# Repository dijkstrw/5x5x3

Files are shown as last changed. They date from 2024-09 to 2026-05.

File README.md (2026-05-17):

5x5x3
-----

My third take on a 5x5 macro keyboard, built on top of ZMK / Zephyr. The board
is a custom 5x5 matrix carried by a nice!nano v2 module, with a rotary encoder
on the side and a 25-LED SK6803 strip behind the keys.

What this repo adds on top of stock ZMK lives in `zmk-config/` and is loaded as
an out-of-tree Zephyr module:

- **Per-key light groups**. Each of the 25 LEDs is assigned to a group
  (`DESKTOP`, `VOLUME`, `HID`, `BATTERY`, `LAYER`, `ENDPOINT`, `PROFILE`) via
  the `zmk,light-group` and `zmk,behavior-led-layout` bindings. The group's
  current value indexes into a per-group HSV palette (`zmk,color-group` +
  `zmk,behavior-hsv`), so the LED grid reflects keyboard state at a glance:
  desktop number, volume level, output endpoint, BLE profile, layer, caps/num
  lock, battery, etc.
- **Color effects**. `src/color-effect.c` implements smooth HSV transitions
  for state changes, so values fade rather than snap.
- **`lightgroup` shell command**. A Zephyr shell over USB CDC ACM
  exposing `lightgroup battery|desktop|endpoint|hid|
  layer|profile|volume <value>` allows the host to drive the LED state
  directly. This is needed to update `desktop` and can be used to
  debug the other states.
- **Custom board**. `boards/dijkstra/5x5x3` defines the
  nice!nano-based matrix, the rotary encoder node, and the SK6803 SPI
  LED strip.

Schematic
---------

A kicad schematic and layout for 2 boards lives in `schematic`. The
bottom board carries the nice!nano v2, battery, on/off switch,
blackmagic/arm swd programming port, and breaks out to connections for
the top board. The top board is carries Kailh v2 low profile switches,
sk6803 leds underneath each switch.

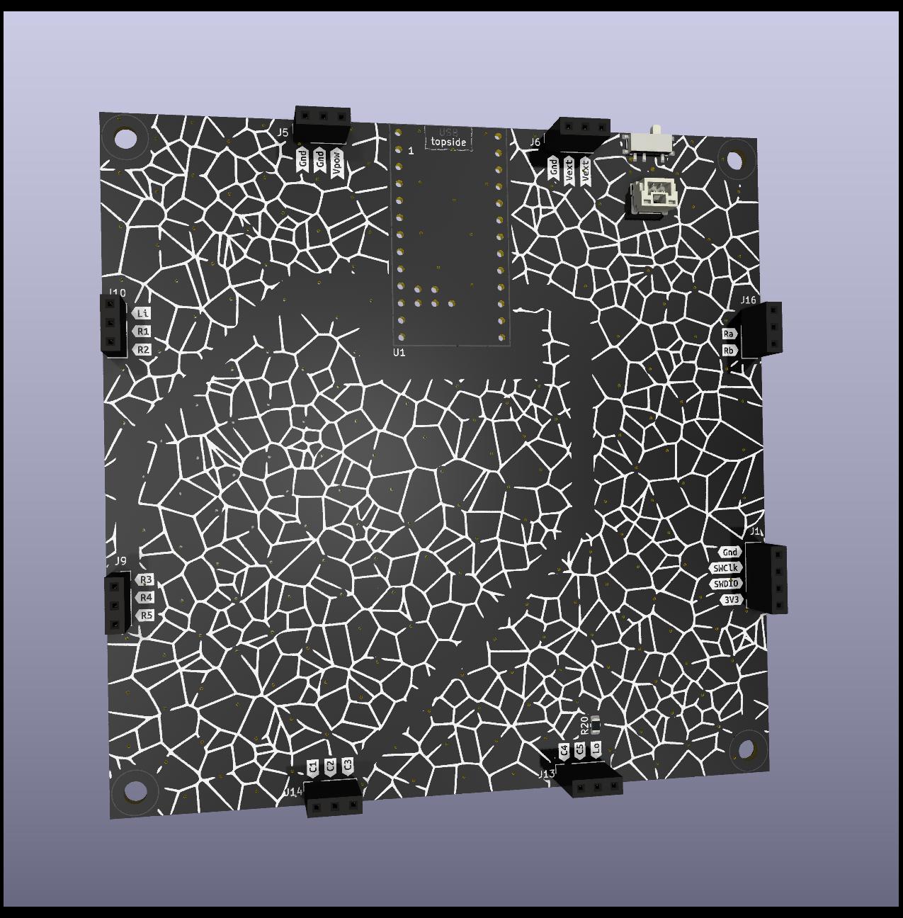
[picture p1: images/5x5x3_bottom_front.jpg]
Bottom board, front

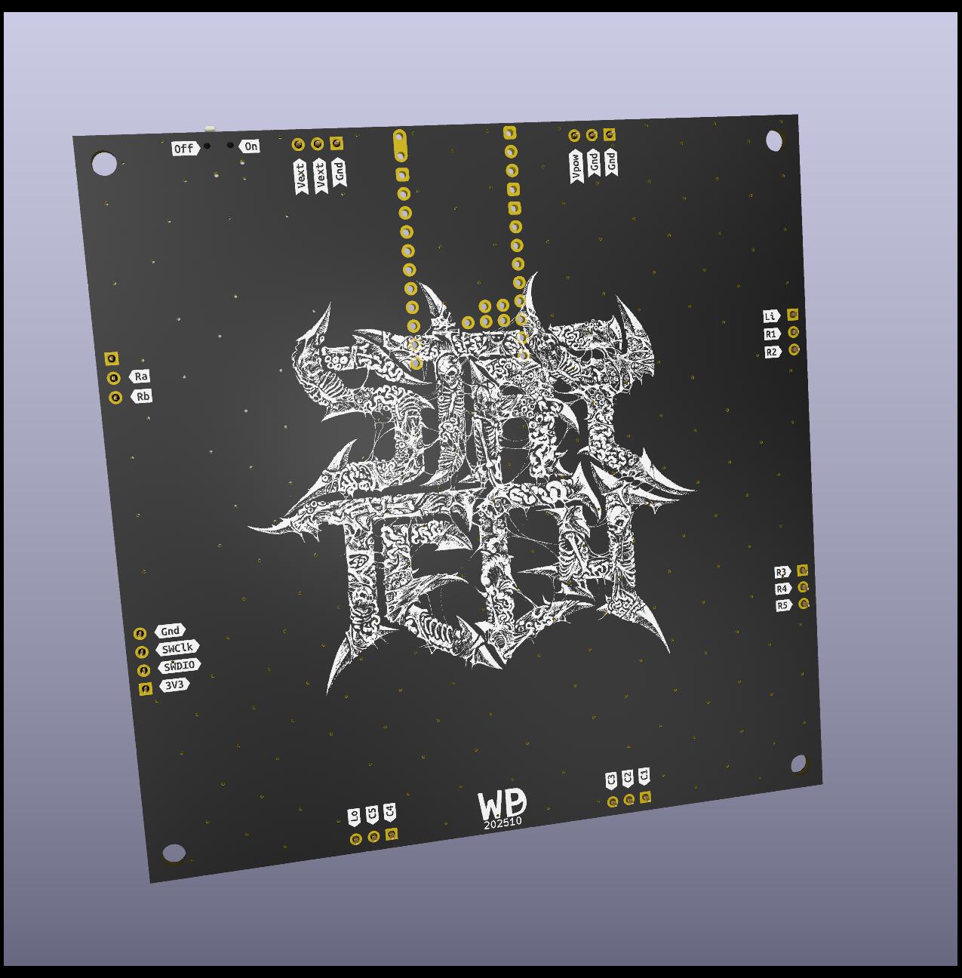
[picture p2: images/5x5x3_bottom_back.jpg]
Bottom board, back

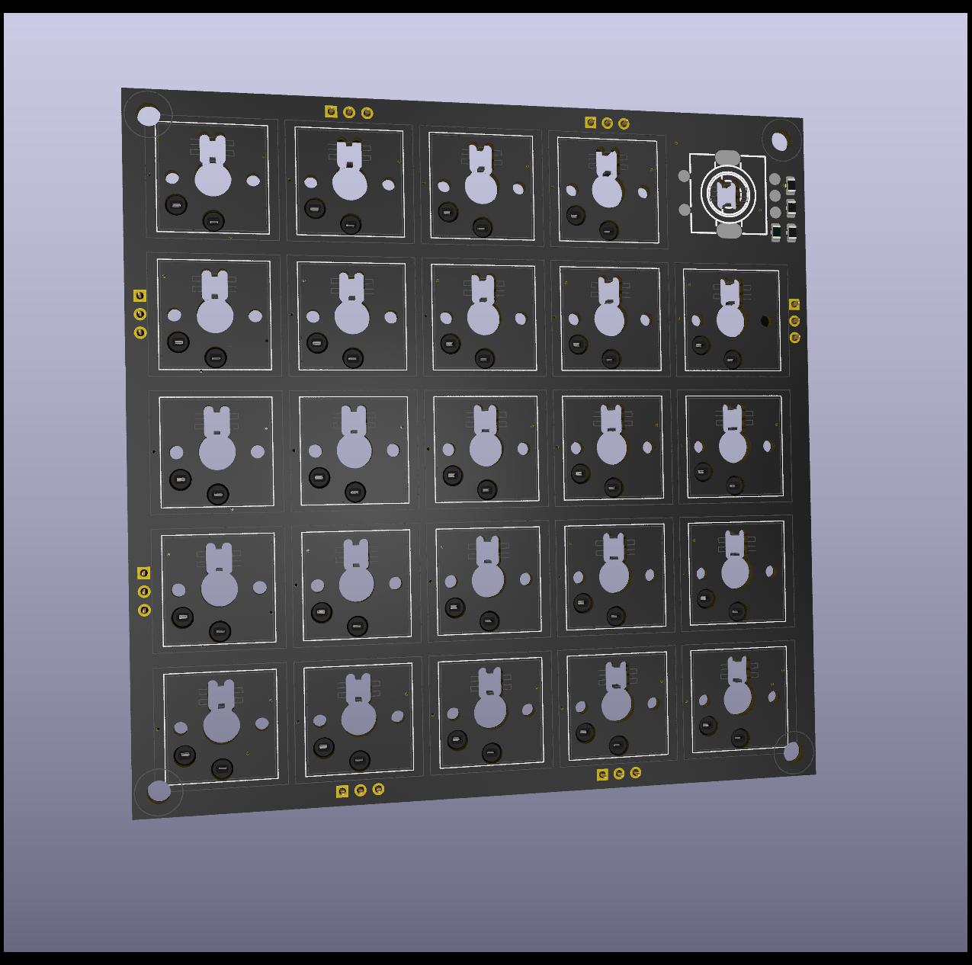
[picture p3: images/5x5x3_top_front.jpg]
Top board, front

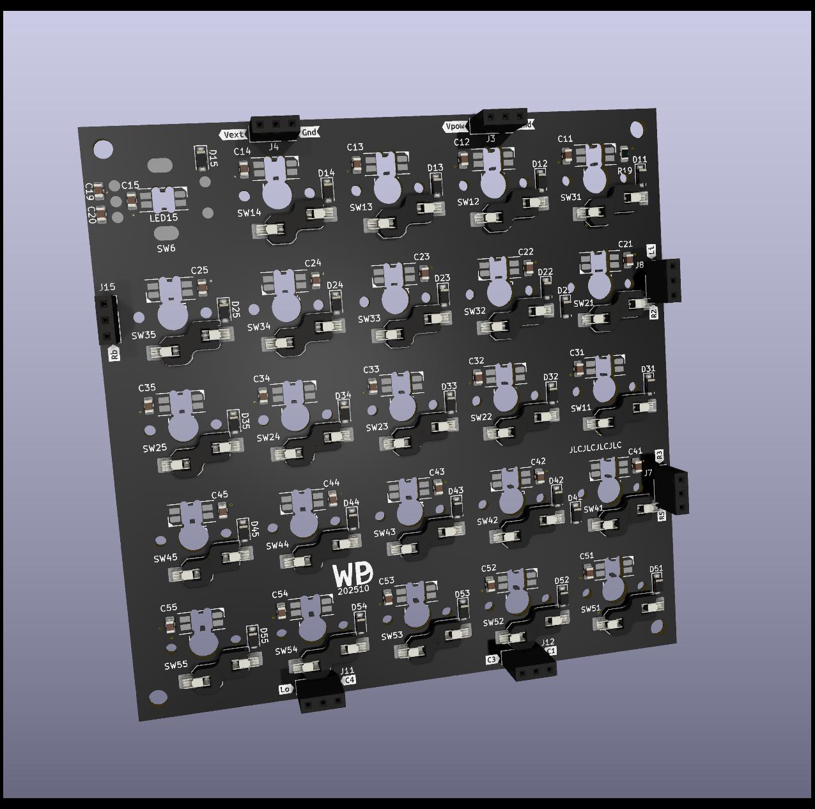
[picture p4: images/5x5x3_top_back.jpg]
Top board, back


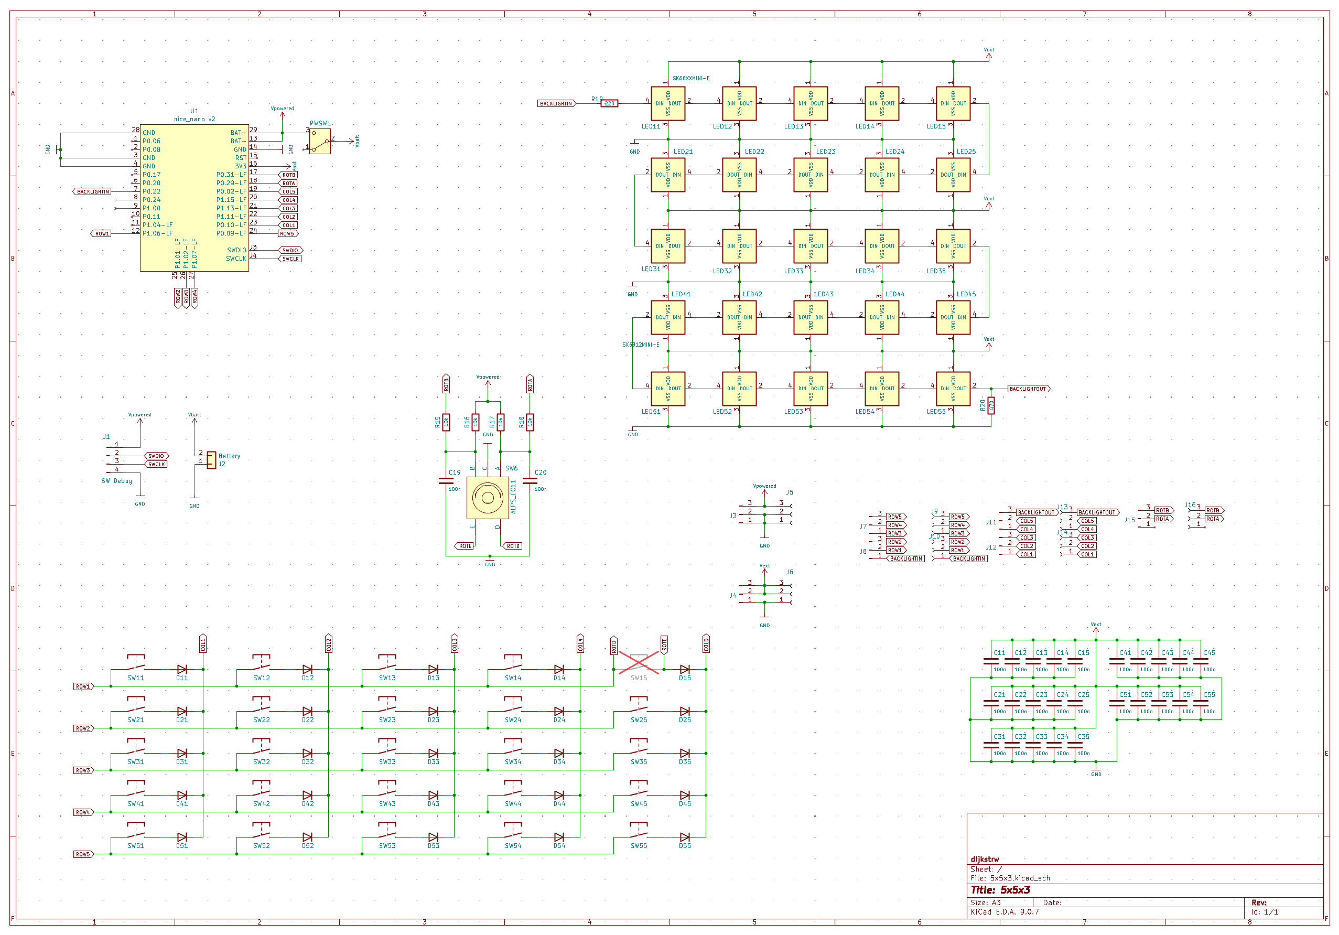
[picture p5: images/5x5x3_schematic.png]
Schematic


Default keymap
--------------

The shipping keymap (`zmk-config/boards/dijkstra/5x5x3/5x5x3.keymap`) is a
small worked example of every custom trait above. Excerpt:

    keymap {
        compatible = "zmk,keymap";
        default_layer {
            bindings = <
                &kp F13       &kp F14       &kp F15       &kp F16       &kp K_MUTE
                &kp F17       &kp F18       &kp F19       &kp F20       &kp F21
                &kp RC(LEFT)  &kp LEFT      &kp K_PP      &kp RIGHT     &kp RC(RIGHT)
                &kp K_APP     &kp C_AL_DOCS &kp C_AL_LOCK &kp C_AL_FILES&kp C_AL_WWW
                &out OUT_TOG  &bt BT_NXT    &kp F22       &kp F23       &kp F24
            >;
            sensor-bindings = <&inc_dec_kp C_VOL_UP C_VOL_DN>;
        };
    };

The bottom-left two keys exercise BLE: `&out OUT_TOG` toggles between USB
and BLE output, `&bt BT_NXT` cycles BLE profile slots. The encoder is wired
through `sensor-bindings` to send `C_VOL_UP` / `C_VOL_DN`.

`ledlayout` maps the physical LED order on the SK6803 strip to the row/col
grid (the strip snakes, so row 1 reverses):

    ledlayout {
        compatible = "zmk,behavior-led-layout";
        bindings = [ 00 01 02 03 04
                     09 08 07 06 05
                     0a 0b 0c 0d 0e
                     13 12 11 10 0f
                     14 15 16 17 18 ];
    };

`lightgroup` assigns each LED to a state-driven group. Here rows 1-2 show the
active desktop, row 3 the volume bar, row 4 caps/num lock + battery, row 5
endpoint / BLE profile / active layer:

    lightgroup {
        compatible = "zmk,light-group";
        default_layer {
            bindings = [ LG_DESKTOP  LG_DESKTOP  LG_DESKTOP  LG_DESKTOP  LG_DESKTOP
                         LG_DESKTOP  LG_DESKTOP  LG_DESKTOP  LG_DESKTOP  LG_DESKTOP
                         LG_VOLUME   LG_VOLUME   LG_VOLUME   LG_VOLUME   LG_VOLUME
                         LG_HID      LG_HID      LG_HID      LG_BATTERY  LG_BATTERY
                         LG_ENDPOINT LG_PROFILE  LG_LAYER    LG_LAYER    LG_LAYER  ];
        };
    };

`colorgroup` provides the HSV palette each group indexes into. For example
battery has five colors representing the 0/25/50/75/100% buckets, desktops
have ten colors for ten desktops, endpoints have three (USB + two BLE):

    colorgroup {
        compatible = "zmk,color-group";
        batterys  { colors = <&hsv HSV_MAGENTA &hsv HSV_RED &hsv HSV_YELLOW &hsv HSV_GREEN &hsv HSV_GREEN>; };
        desktops  { colors = <&hsv HSV_CHARTREUSE &hsv HSV_YELLOW &hsv HSV_ROSE &hsv HSV_VIOLET &hsv HSV_AZURE
                              &hsv HSV_MAGENTA &hsv HSV_VOLTA &hsv HSV_CYAN &hsv HSV_SPRING &hsv HSV_CRIMSON>; };
        endpoints { colors = <&hsv HSV_RED &hsv HSV_GREEN &hsv HSV_BLUE>; };
        ...
    };

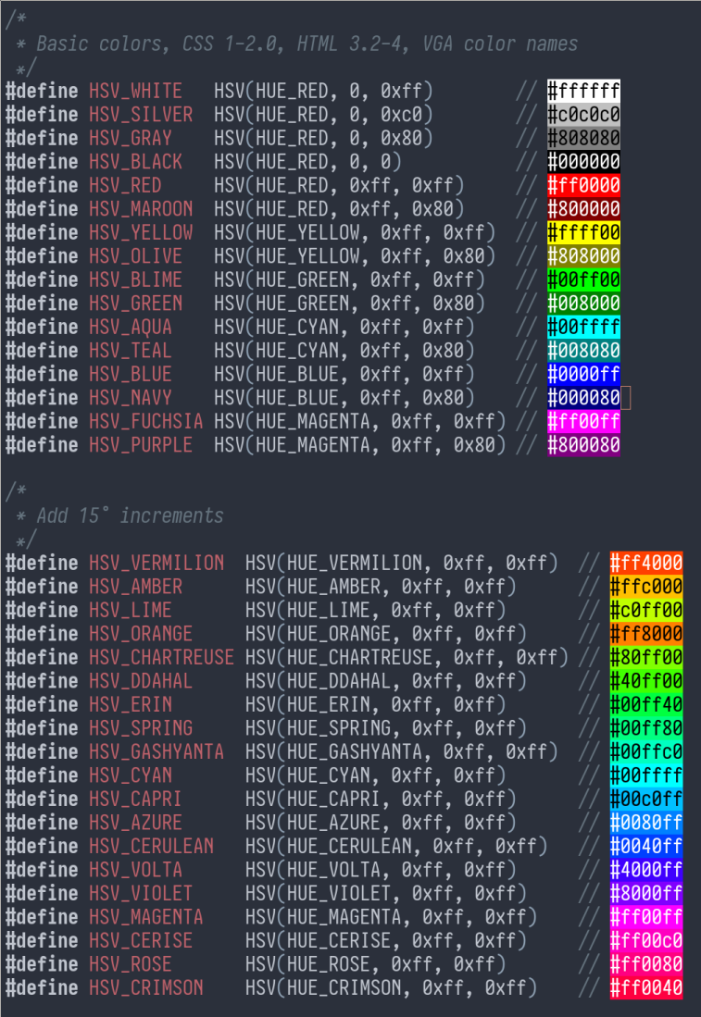
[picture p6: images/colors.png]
Color palette


Together: ZMK events (layer change, BLE profile change, battery level,
HID caps/num indicator, serial cli update) update each group's value,
the group's current value picks a color from the palette, and the LEDs
assigned to that group on the active layer fade to it.

Building
--------

5x5x3 assumes you have `direnv` and that `.envrc` is automatically
sourced. This will setup a local `.venv` and install `west` using
`uv`.

After that you need `zmk` for keyboard source firmware files, `zephyr`
for the rtos source, which includes an usb and bt stack, and the NRF52
hal, and finally an SDK for cross-compiling to NRF52.

``` shell
make init
```

Retrieves the `zmk` and `zephyr` source, and installs all python
modules we need for building.

If you have not developed with `zephyr` before you also need a Zephyr
SDK. Go to the `zmk` directory and run `west sdk install`.

Note that your source directory will balloon to between 1.5 and almost
5GB due to all the downloaded dependencies.

With all deps loaded;

``` shell
make build
```

Will build a lean production firmware that contains;
- BLE
- USB
- kscan in interrupt mode
- shell with just the lightgroup command.

``` shell
make debug
```

Will build a debug firmwire with:
- more logging
- kernel/gpio/bt/settings shells
- RTT over the SWD probe
- polling kscan

``` shell
make flash
```

Will attempt to flash the resulting firmware to the board via a Black
Magic Probe at `blackmagic.lan:2022`.

``` shell
make serial
```

Will open a terminal to the keyboard's USB CDC ACM, after it has
attached e.g. via USB.

Debugging
---------
Enable debug logging for zmk:

    log enable dbg zmk

Look at zephyr kernel threads and the amount of stack use of each:

    kernel thread list
    kernel thread stacks

Links
-----

- [ZMK](https://github.com/zmkfirmware/zmk): wireless keyboard firmware
- [Zephyr](https://github.com/zephyrproject-rtos/zephyr): RTOS that ZMK is
  built on
- [Black Magic Probe](https://github.com/blackmagic-debug/blackmagic): open
  source SWD/JTAG debug probe firmware used for flashing and RTT

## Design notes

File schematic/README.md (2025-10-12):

Third iteration of my 5x5;
- based on zmk, using the nicenano2 board / Supermini RF52840

Questions:
- Can the LDO keep up with 25 sk6803s?

25 * 5mA = 125mA, within range of charger and ldo on nicenano2

- Where are the specific pins for spi / i2c?

RF52840 can reconfigure its pins, so can be assigned to work well with
whatever layout we want.

Other keyboard projects of interest:

- foostan: corne / crkb: the first time I saw sk6812 in mini-e
  variant.

  https://github.com/foostan/kbd
  https://github.com/foostan/crkbd

  MIT license, parts reused:
  - Source of YS-SK6812-MINI-E schematic symbol, and 3d step model.

- Stefan Hamminga: sk6812mini model that models the underside of the
  package best.

- Spamwax: nicenano v2 step model

  https://www.printables.com/model/1181384-nicenano-mcu/files

- Supermini NRF52840 site

  https://wiki.icbbuy.com/doku.php?id=developmentboard:nrf52840

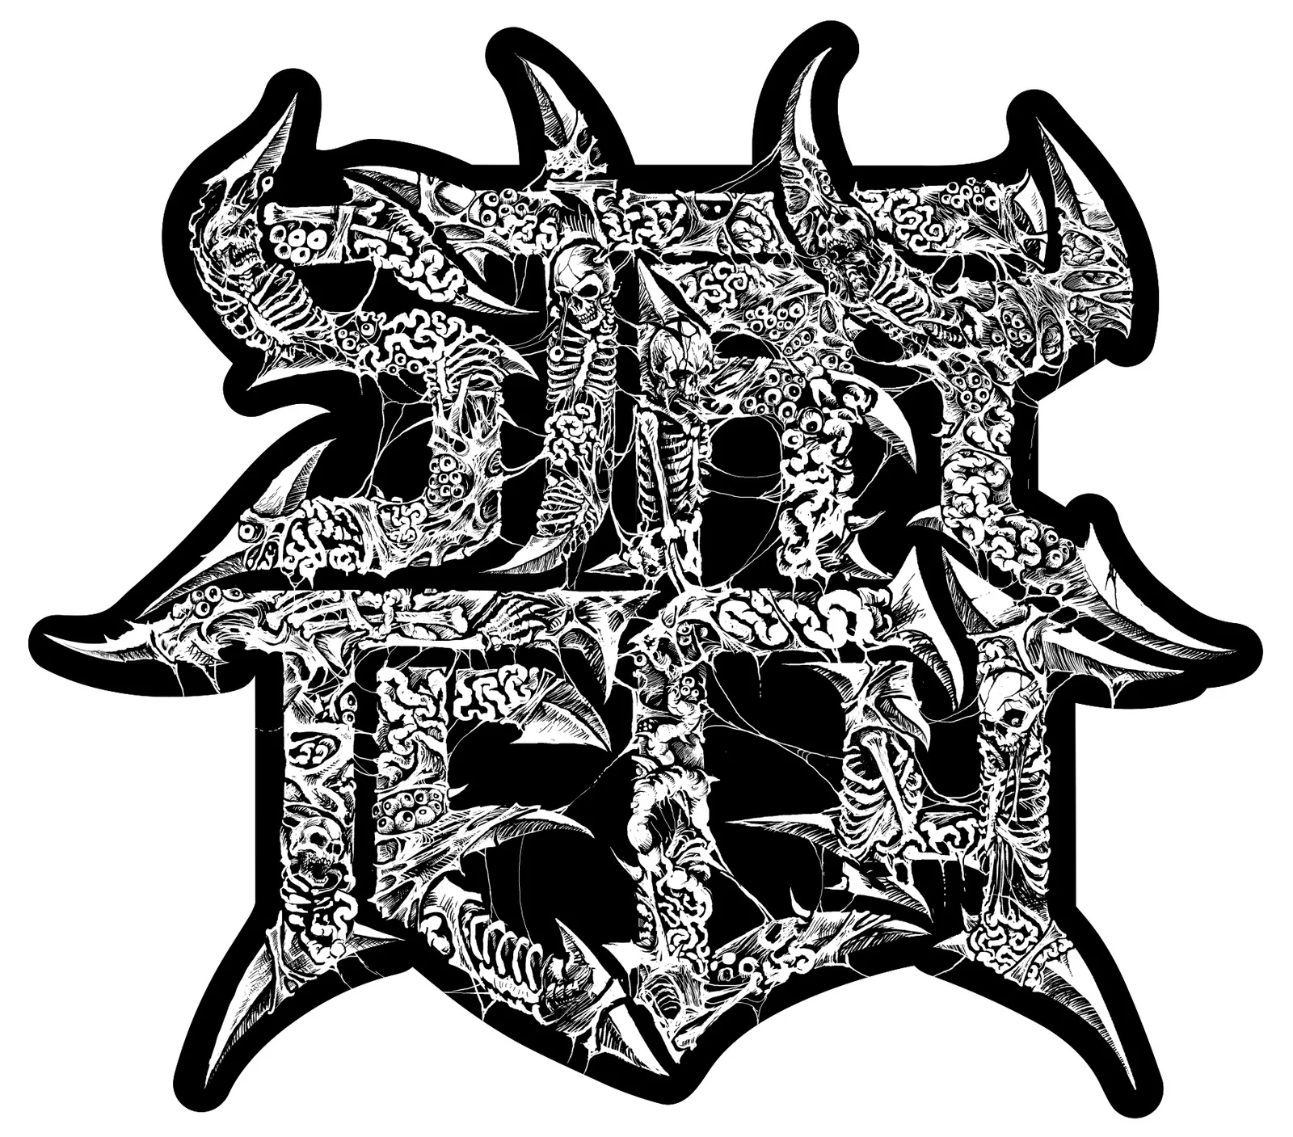
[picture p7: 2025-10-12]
schematic/images/staytech.png

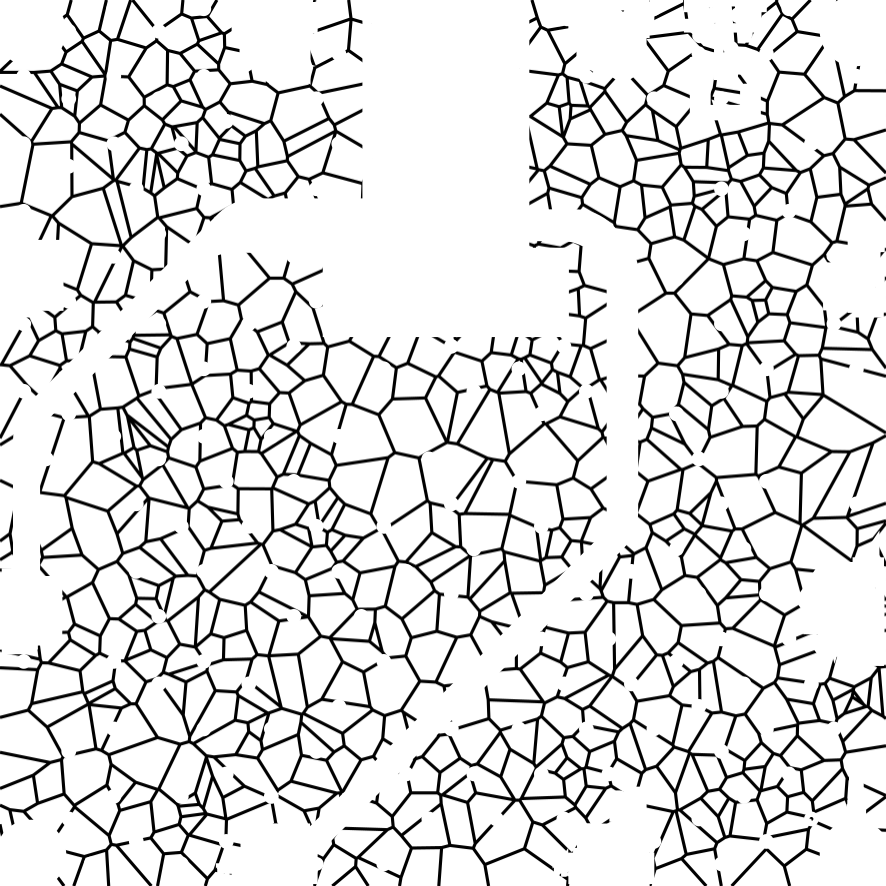
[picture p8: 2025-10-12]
schematic/images/f voronoi.png

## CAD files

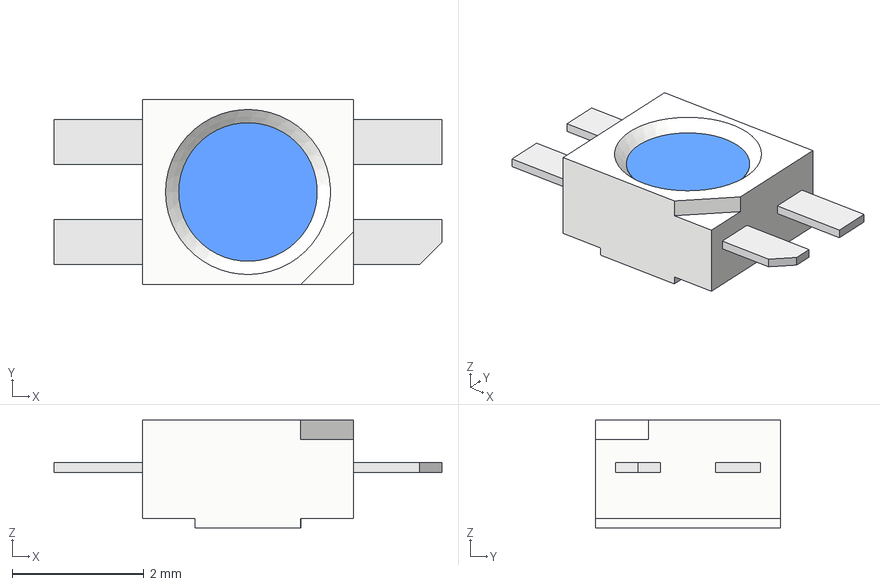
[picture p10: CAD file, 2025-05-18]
schematic/3dmodels/YS-SK6812MINI-E.step
5.88 x 2.80 x 1.63 mm

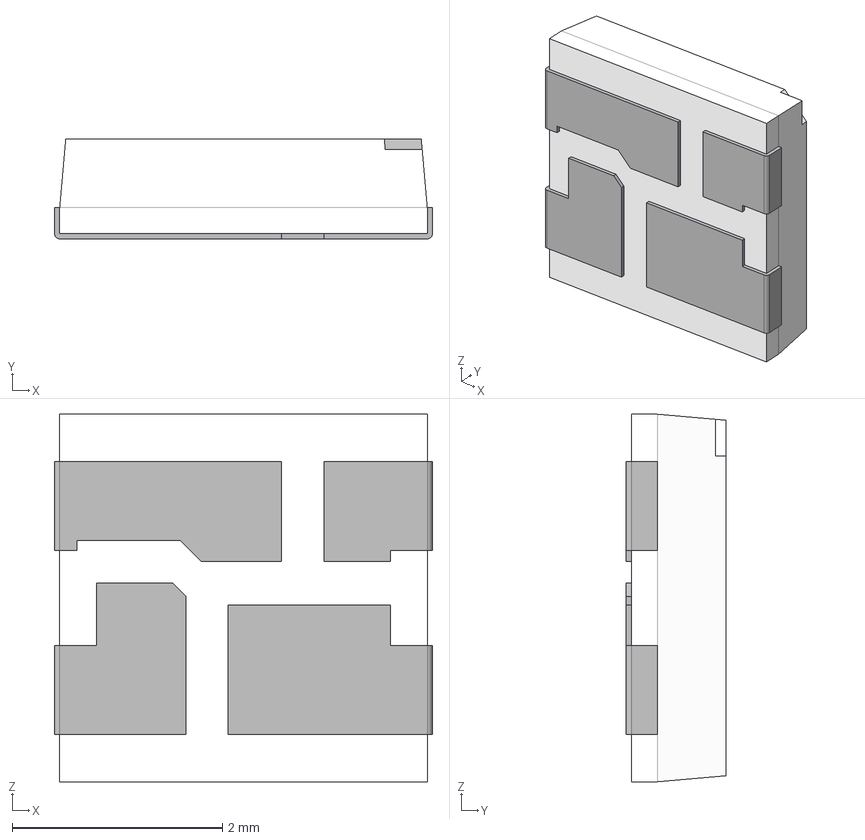
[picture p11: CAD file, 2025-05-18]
schematic/3dmodels/SK6812_Mini.step
3.60 x 0.95 x 3.50 mm
SK6812_Mini
SK6812_Mini004
SK6812_Mini003
SK6812_Mini005
SK6812_Mini002
SK6812_Mini001

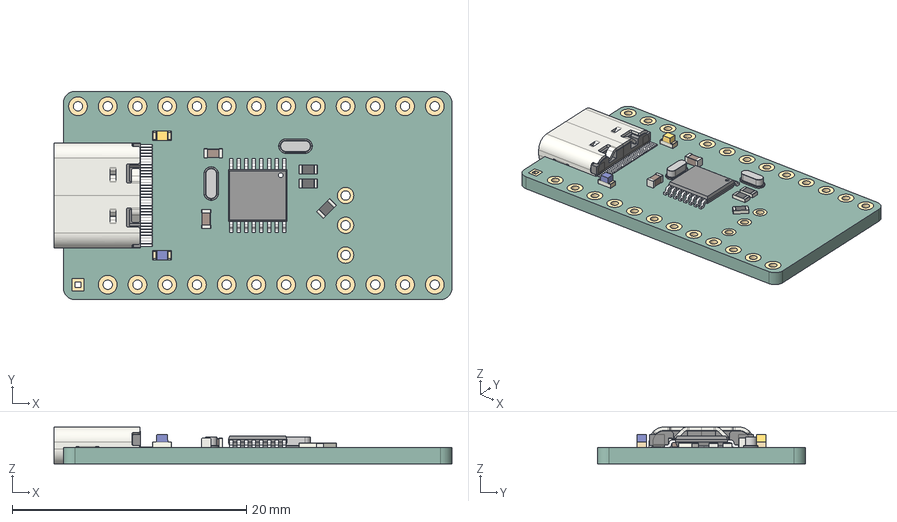
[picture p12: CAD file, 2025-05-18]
schematic/3dmodels/nicenano-v2.step
34.0 x 17.8 x 3.16 mm
nice!nano v1.0_1
USB_C_Receptacle_16P_TopMnt_Horizontal_GCT_USB4105-xx-A
USB_C_Receptacle_16P_TopMnt_Horizontal_GCT_USB4105-xx-A001
USB_C_Receptacle_16P_TopMnt_Horizontal_GCT_USB4105-xx-A002
USB_C_Receptacle_16P_TopMnt_Horizontal_GCT_USB4105-xx-A003
USB_C_Receptacle_16P_TopMnt_Horizontal_GCT_USB4105-xx-A004
USB_C_Receptacle_16P_TopMnt_Horizontal_GCT_USB4105-xx-A005
USB_C_Receptacle_16P_TopMnt_Horizontal_GCT_USB4105-xx-A006
USB_C_Receptacle_16P_TopMnt_Horizontal_GCT_USB4105-xx-A007
USB_C_Receptacle_16P_TopMnt_Horizontal_GCT_USB4105-xx-A008
USB_C_Receptacle_16P_TopMnt_Horizontal_GCT_USB4105-xx-A009
USB_C_Receptacle_16P_TopMnt_Horizontal_GCT_USB4105-xx-A010
USB_C_Receptacle_16P_TopMnt_Horizontal_GCT_USB4105-xx-A011
USB_C_Receptacle_16P_TopMnt_Horizontal_GCT_USB4105-xx-A012
USB_C_Receptacle_16P_TopMnt_Horizontal_GCT_USB4105-xx-A013
USB_C_Receptacle_16P_TopMnt_Horizontal_GCT_USB4105-xx-A014
USB_C_Receptacle_16P_TopMnt_Horizontal_GCT_USB4105-xx-A015
USB_C_Receptacle_16P_TopMnt_Horizontal_GCT_USB4105-xx-A016
USB_C_Receptacle_16P_TopMnt_Horizontal_GCT_USB4105-xx-A017
USB_C_Receptacle_16P_TopMnt_Horizontal_GCT_USB4105-xx-A018
USB_C_Receptacle_16P_TopMnt_Horizontal_GCT_USB4105-xx-A019
USB_C_Receptacle_16P_TopMnt_Horizontal_GCT_USB4105-xx-A020
USB_C_Receptacle_16P_TopMnt_Horizontal_GCT_USB4105-xx-A021
USB_C_Receptacle_16P_TopMnt_Horizontal_GCT_USB4105-xx-A022
USB_C_Receptacle_16P_TopMnt_Horizontal_GCT_USB4105-xx-A023
USB_C_Receptacle_16P_TopMnt_Horizontal_GCT_USB4105-xx-A024
USB_C_Receptacle_16P_TopMnt_Horizontal_GCT_USB4105-xx-A025
USB_C_Receptacle_16P_TopMnt_Horizontal_GCT_USB4105-xx-A026
USB_C_Receptacle_16P_TopMnt_Horizontal_GCT_USB4105-xx-A027
USB_C_Receptacle_16P_TopMnt_Horizontal_GCT_USB4105-xx-A028
USB_C_Receptacle_16P_TopMnt_Horizontal_GCT_USB4105-xx-A029
USB_C_Receptacle_16P_TopMnt_Horizontal_GCT_USB4105-xx-A030
USB_C_Receptacle_16P_TopMnt_Horizontal_GCT_USB4105-xx-A031
USB_C_Receptacle_16P_TopMnt_Horizontal_GCT_USB4105-xx-A032
USB_C_Receptacle_16P_TopMnt_Horizontal_GCT_USB4105-xx-A033
USB_C_Receptacle_16P_TopMnt_Horizontal_GCT_USB4105-xx-A034
USB_C_Receptacle_16P_TopMnt_Horizontal_GCT_USB4105-xx-A035
Pin9
Pin10
Pin12
Pin11
Pin13
Pin14
Pin15
Pin16
Pin8
Pin7
Pin6
Pin5
Pin4
Pin3
Pin2
Pin1
LED_0603_1608Metric_ON
C_0603_1608Metric x 2
LED_0603_1608Metric_ON_1
Crystal Oscillator x 2
R_0603_1608Metric x 4

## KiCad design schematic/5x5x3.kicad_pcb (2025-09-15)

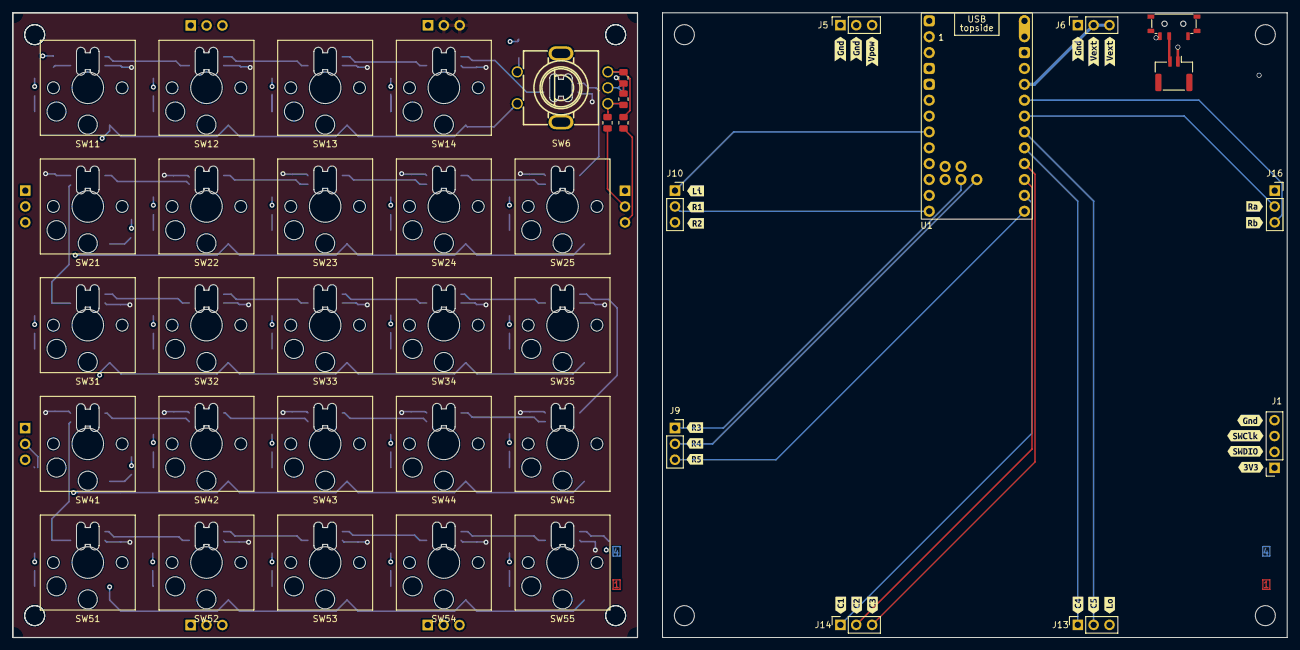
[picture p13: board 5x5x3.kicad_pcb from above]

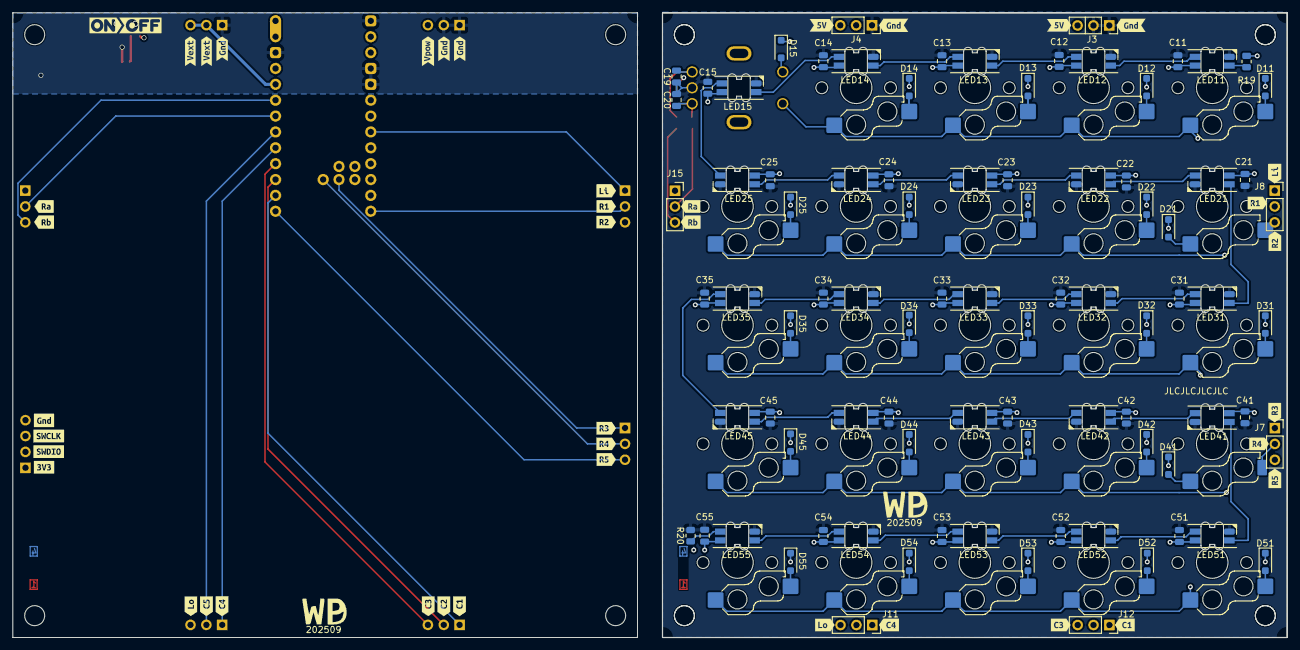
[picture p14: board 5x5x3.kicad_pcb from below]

Board: 4 copper layers, 100.0 x 100.0 mm, 192 parts (128 on the bottom side), 72 nets.

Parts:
C11, C12, C13, C14, C15, C19, C20, C21, C22, C23, C24, C25, C31, C32, C33, C34, C35, C41, C42, C43, C44, C45, C51, C52, C53, C54, C55: 100n; C_0805_2012Metric
D11, D12, D13, D14, D15, D21, D22, D23, D24, D25, D31, D32, D33, D34, D35, D41, D42, D43, D44, D45, D51, D52, D53, D54, D55: 1N4148; D_SOD-123F
J1: SW Debug; PinSocket_1x04_P2.54mm_Vertical
J2: Battery; JST_GH_BM02B-GHS-TBT_1x02-1MP_P1.25mm_Vertical
J3, J4, J7, J8, J11, J12, J15: Conn_01x03_Male; PinSocket_1x03_P2.54mm_Vertical
J5, J6, J9, J10, J13, J14, J16: Conn_01x03_Female; PinSocket_1x03_P2.54mm_Vertical
LED11: SK68XXMINI-E; YS-SK6812MINI-E
LED12, LED13, LED14, LED15, LED21, LED22, LED23, LED24, LED25, LED31, LED32, LED33, LED34, LED35, LED41, LED42, LED43, LED44, LED45, LED51, LED52, LED53, LED54, LED55: SK6812MINI-E; YS-SK6812MINI-E
PWSW1: SW_SPST; SW_MSK12C02-HB
R15, R16, R17, R18: 10k; R_0805_2012Metric
R19: 220; R_0805_2012Metric
R20: 470; R_0805_2012Metric
SW6: ALPS_EC11; SW-TH_EC11XXXXXXXX
SW11, SW12, SW13, SW14, SW21, SW22, SW23, SW24, SW25, SW31, SW32, SW33, SW34, SW35, SW41, SW42, SW43, SW44, SW45, SW51, SW52, SW53, SW54, SW55: SW; SW_Hotswap_Kailh_Choc_V1V2_1.00u
U1: nice_nano v2; nice_nano_AH_USBup
kibuzzard-62AF6B0E: G***; kibuzzard-62AF6B0E
kibuzzard-62AF6B7C, kibuzzard-62AF6B7C#2: G***; kibuzzard-62AF6B7C
kibuzzard-62AF6B38, kibuzzard-62AF6B38#2: G***; kibuzzard-62AF6B38
kibuzzard-62AF6BA3, kibuzzard-62AF6BA3#2: G***; kibuzzard-62AF6BA3
kibuzzard-62AF6BAD, kibuzzard-62AF6BAD#2: G***; kibuzzard-62AF6BAD
kibuzzard-62AF6BF3: G***; kibuzzard-62AF6BF3
kibuzzard-62AF6D1E, kibuzzard-62AF6D1E#2: G***; kibuzzard-62AF6D1E
kibuzzard-62AF6DB1, kibuzzard-62AF6DB1#2: G***; kibuzzard-62AF6DB1
kibuzzard-62AF6E15: G***; kibuzzard-62AF6E15
kibuzzard-62AF6E21: G***; kibuzzard-62AF6E21
kibuzzard-62AF6EB6: G***; kibuzzard-62AF6EB6
kibuzzard-62AF6EDD: G***; kibuzzard-62AF6EDD
kibuzzard-62AF6F00: G***; kibuzzard-62AF6F00
kibuzzard-62AF6F11: G***; kibuzzard-62AF6F11
kibuzzard-62AF7A14: G***; kibuzzard-62AF7A14
kibuzzard-62AF7A28: G***; kibuzzard-62AF7A28
kibuzzard-62AF7A49: G***; kibuzzard-62AF7A49
kibuzzard-62AF7A56: G***; kibuzzard-62AF7A56
kibuzzard-62AF7CA9: G***; kibuzzard-62AF7CA9
kibuzzard-62AF7CCF: G***; kibuzzard-62AF7CCF
kibuzzard-62AF74B5: G***; kibuzzard-62AF74B5
kibuzzard-62AF74BF: G***; kibuzzard-62AF74BF
kibuzzard-62AF74C8: G***; kibuzzard-62AF74C8
kibuzzard-62AF749F: G***; kibuzzard-62AF749F
kibuzzard-62AF7487: G***; kibuzzard-62AF7487
kibuzzard-62AF7492: G***; kibuzzard-62AF7492
kibuzzard-62B6DFF3: G***; kibuzzard-62B6DFF3
kibuzzard-62B6E005: G***; kibuzzard-62B6E005
kibuzzard-68B42C08, kibuzzard-68B42C08#2: G***; kibuzzard-68B42C08
kibuzzard-68B471AC: G***; kibuzzard-68B471AC
kibuzzard-68B471BD: G***; kibuzzard-68B471BD
kibuzzard-68B471DE: G***; kibuzzard-68B471DE
kibuzzard-68B471FE: G***; kibuzzard-68B471FE
kibuzzard-68B472A1: G***; kibuzzard-68B472A1
kibuzzard-68B472AB: G***; kibuzzard-68B472AB
kibuzzard-68B4713C, kibuzzard-68B4713C#2, kibuzzard-68B4713C#3, kibuzzard-68B4713C#4, kibuzzard-68B4713C#5, kibuzzard-68B4713C#6: G***; kibuzzard-68B4713C
kibuzzard-68B4715A, kibuzzard-68B4715A#2: G***; kibuzzard-68B4715A
kibuzzard-68B4721A: G***; kibuzzard-68B4721A
kibuzzard-68B4724C: G***; kibuzzard-68B4724C
kibuzzard-68B4727C: G***; kibuzzard-68B4727C
kibuzzard-68B4728F: G***; kibuzzard-68B4728F
kibuzzard-68B4733A: G***; kibuzzard-68B4733A
kibuzzard-68B47169, kibuzzard-68B47169#2: G***; kibuzzard-68B47169
kibuzzard-68B47213: G***; kibuzzard-68B47213
kibuzzard-68B47243: G***; kibuzzard-68B47243
kibuzzard-68B47320: G***; kibuzzard-68B47320
kibuzzard-68B47329: G***; kibuzzard-68B47329
kibuzzard-68B47332: G***; kibuzzard-68B47332
kibuzzard-68B47346: G***; kibuzzard-68B47346
kibuzzard-68B47351: G***; kibuzzard-68B47351
kibuzzard-685E981C: G***; kibuzzard-685E981C
kibuzzard-685E9829: G***; kibuzzard-685E9829

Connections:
BACKLIGHTIN: J8.1, J10.1, R19.2, U1.7 (P0.22)
BACKLIGHTOUT: J11.3, J13.3, LED55.2 (DOUT), R20.1
COL1: D11.1 (K), D21.1 (K), D31.1 (K), D41.1 (K), D51.1 (K), J12.1, J14.1, U1.23 (P0.10-LF)
COL2: D12.1 (K), D22.1 (K), D32.1 (K), D42.1 (K), D52.1 (K), J12.2, J14.2, U1.22 (P1.11-LF)
COL3: D13.1 (K), D23.1 (K), D33.1 (K), D43.1 (K), D53.1 (K), J12.3, J14.3, U1.21 (P1.13-LF)
COL4: D14.1 (K), D24.1 (K), D34.1 (K), D44.1 (K), D54.1 (K), J11.1, J13.1, U1.20 (P1.15-LF)
COL5: D15.1 (K), D25.1 (K), D35.1 (K), D45.1 (K), D55.1 (K), J11.2, J13.2, U1.19 (P0.02-LF)
GND: C11.2, C12.2, C13.2, C14.2, C15.2, C19.2, C20.2, C21.2, C22.2, C23.2, C24.2, C25.2, C31.2, C32.2, C33.2, C34.2, C35.2, C41.2, C42.2, C43.2, C44.2, C45.2, C51.2, C52.2, C53.2, C54.2, C55.2, J1.4, J2.1, J3.1, J3.2, J4.1, J5.1, J5.2, J6.1, LED11.3 (VSS), LED12.3 (VSS), LED13.3 (VSS), LED14.3 (VSS), LED15.3 (VSS), LED21.3 (VSS), LED22.3 (VSS), LED23.3 (VSS), LED24.3 (VSS), LED25.3 (VSS), LED31.3 (VSS), LED32.3 (VSS), LED33.3 (VSS), LED34.3 (VSS), LED35.3 (VSS), LED41.3 (VSS), LED42.3 (VSS), LED43.3 (VSS), LED44.3 (VSS), LED45.3 (VSS), LED51.3 (VSS), LED52.3 (VSS), LED53.3 (VSS), LED54.3 (VSS), LED55.3 (VSS), R20.2, SW6.C, U1.3 (GND), U1.4 (GND), U1.14 (GND), U1.28 (GND)
unnamed: C19.1, R15.2, R16.2, SW6.B
unnamed: C20.1, R17.2, R18.2, SW6.A
unnamed: D11.2 (A), SW11.2
unnamed: D12.2 (A), SW12.2
unnamed: D13.2 (A), SW13.2
unnamed: D14.2 (A), SW14.2
unnamed: D21.2 (A), SW21.1
unnamed: D22.2 (A), SW22.2
unnamed: D23.2 (A), SW23.2
unnamed: D24.2 (A), SW24.2
unnamed: D25.2 (A), SW25.2
unnamed: D31.2 (A), SW31.2
unnamed: D32.2 (A), SW32.2
unnamed: D33.2 (A), SW33.2
unnamed: D34.2 (A), SW34.2
unnamed: D35.2 (A), SW35.2
unnamed: D41.2 (A), SW41.1
unnamed: D42.2 (A), SW42.2
unnamed: D43.2 (A), SW43.2
unnamed: D44.2 (A), SW44.2
unnamed: D45.2 (A), SW45.2
unnamed: D51.2 (A), SW51.2
unnamed: D52.2 (A), SW52.2
unnamed: D53.2 (A), SW53.2
unnamed: D54.2 (A), SW54.2
unnamed: D55.2 (A), SW55.2
unnamed: LED11.4 (DIN), R19.1
unnamed: LED11.2 (DOUT), LED12.4 (DIN)
unnamed: LED12.2 (DOUT), LED13.4 (DIN)
unnamed: LED13.2 (DOUT), LED14.4 (DIN)
unnamed: LED14.2 (DOUT), LED15.4 (DIN)
unnamed: LED15.2 (DOUT), LED25.4 (DIN)
unnamed: LED21.4 (DIN), LED22.2 (DOUT)
unnamed: LED21.2 (DOUT), LED31.4 (DIN)
unnamed: LED22.4 (DIN), LED23.2 (DOUT)
unnamed: LED23.4 (DIN), LED24.2 (DOUT)
unnamed: LED24.4 (DIN), LED25.2 (DOUT)
unnamed: LED31.2 (DOUT), LED32.4 (DIN)
unnamed: LED32.2 (DOUT), LED33.4 (DIN)
unnamed: LED33.2 (DOUT), LED34.4 (DIN)
unnamed: LED34.2 (DOUT), LED35.4 (DIN)
unnamed: LED35.2 (DOUT), LED45.4 (DIN)
unnamed: LED41.4 (DIN), LED42.2 (DOUT)
unnamed: LED41.2 (DOUT), LED51.4 (DIN)
unnamed: LED42.4 (DIN), LED43.2 (DOUT)
unnamed: LED43.4 (DIN), LED44.2 (DOUT)
unnamed: LED44.4 (DIN), LED45.2 (DOUT)
unnamed: LED51.2 (DOUT), LED52.4 (DIN)
unnamed: LED52.2 (DOUT), LED53.4 (DIN)
unnamed: LED53.2 (DOUT), LED54.4 (DIN)
unnamed: LED54.2 (DOUT), LED55.4 (DIN)
ROTA: J15.2, J16.2, R18.1, U1.18 (P0.29-LF)
ROTB: J15.3, J16.3, R15.1, U1.17 (P0.31-LF)
ROTD: J8.2, J10.2, SW6.D, SW11.1, SW12.1, SW13.1, SW14.1, U1.12 (P1.06-LF)
ROTE: D15.2 (A), SW6.E
ROW2: J8.3, J10.3, SW21.2, SW22.1, SW23.1, SW24.1, SW25.1, U1.25 (P1.01-LF)
ROW3: J7.1, J9.1, SW31.1, SW32.1, SW33.1, SW34.1, SW35.1, U1.26 (P1.02-LF)
ROW4: J7.2, J9.2, SW41.2, SW42.1, SW43.1, SW44.1, SW45.1, U1.27 (P1.07-LF)
ROW5: J7.3, J9.3, SW51.1, SW52.1, SW53.1, SW54.1, SW55.1, U1.24 (P0.09-LF)
SWCLK: J1.3, U1.J4 (SWCLK)
SWDIO: J1.2, U1.J3 (SWDIO)
Vbatt: J2.2, PWSW1.2 (B)
Vext: C11.1, C12.1, C13.1, C14.1, C15.1, C21.1, C22.1, C23.1, C24.1, C25.1, C31.1, C32.1, C33.1, C34.1, C35.1, C41.1, C42.1, C43.1, C44.1, C45.1, C51.1, C52.1, C53.1, C54.1, C55.1, J4.2, J4.3, J6.2, J6.3, LED11.1 (VDD), LED12.1 (VDD), LED13.1 (VDD), LED14.1 (VDD), LED15.1 (VDD), LED21.1 (VDD), LED22.1 (VDD), LED23.1 (VDD), LED24.1 (VDD), LED25.1 (VDD), LED31.1 (VDD), LED32.1 (VDD), LED33.1 (VDD), LED34.1 (VDD), LED35.1 (VDD), LED41.1 (VDD), LED42.1 (VDD), LED43.1 (VDD), LED44.1 (VDD), LED45.1 (VDD), LED51.1 (VDD), LED52.1 (VDD), LED53.1 (VDD), LED54.1 (VDD), LED55.1 (VDD), U1.16 (3V3)
Vpowered: J1.1, J3.3, J5.3, PWSW1.3 (C), R16.1, R17.1, U1.13 (BAT+), U1.29 (BAT+)

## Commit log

2024-09-06 Started with new zmk choc 5x5
    [5x5x3.kicad_sch]
2024-09-08 Moving to zmk-config board config
2024-09-14 First valid configuration
    Lacks a lot of things, but does allow me to validate the 5x5 layout
    and pin reassignments.
2025-01-26 add ledstrip via spi
    - spi0 at the arduino micro side ends up on p0.10 in nice nano
    land. This pin is lf, and might interfere with the antenna according
    to nordic.
    - spi0 has a hardware issue that requires an enabled sck pin on the
    nrf52840. Moving to spi3 because that does not have that issue.
    - make sure to set status to okay to enable driver...
2025-02-09 Add HSV color configuration in keymap
    First steps towards a custom driver that has the notion of lightgroups
    to show what the status according to the keyboard is.
2025-02-22 Device configuration is entered, but storage definitions are off
    So we have a start!
2025-02-28 Updated device configuration
    Learned a couple of dts attributes:
    - all items have to have a definition of how big they are
    - inside zmk this is handled by specifying for leaf behaviors how many
    #binding-cells they are
    - which also explains the use and overloading of the word binding
2025-03-30 First light on light-group implementation
    - dts is parsed and configured, but not used yet
    - our own timer and worker are called
    Still, after much horsing about -- success!
2025-04-06 First apply according to light groups
    Note that each light group shows you a status for something, and
    that something as an input (e.g. current volume, current hid,
    current endpoint) are missing.
2025-04-17 Rewrite similar devicetree color ranges into one statement
    This shows much clearer what we pull out of device tree than the
    previous wall of text, where the crucial bits were scattered over
    the page.
2025-04-18 Add battery event handling
2025-04-19 Deal with power: state at on/usb powered/ble/idle
    The defaults:
    - on start: on
    - on usb powered: on
    - on idle: off
    - on usb no power: off
    Also clean up taking arguments from the shell. Adjustment to max group
    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
2025-04-20 Simplify power control logic
    The previous power management was overly complex and unintuitive. Disabling external power persisted even when USB power was available and the device was idle, leading to confusion (e.g., no lights d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
    This commit simplifies the logic:
    - USB power: Lights on.
    - Idle: Lights off.
    - USB power loss: Lights off.
2025-04-20 First stab at a serial connector using rust
2025-04-26 Rewrite to susanoo to c
    I found the rust way to complex and busy with rust specific problems
    that obscured the problem that I'm trying to solve.
    This is a simple c approach; again, the python version is more
    powerful, somewhat similar in complexity to read, so going to mull
    over this some more.
2025-04-27 Fix BLE-less compilation
    BLE has real-world timing constraints and will break if we lose track
    of time because we are horsing about in the debugger.
    BLE-less builds can be debugged at will.
2025-04-28 Fixed continuous range calculations
    It took some time for me to understand that the spaces between
    successive colors are the buckets. So the original code had a off by
    one error.
    Also improved the battery color shading to my eye. Battery group will
    stay green from roughly 60% to 100% and change to worrying shades
    (first red, then when it is really important that you seek external
    power purple) after that.
2025-04-28 Map battery percentages to frac8_t
    We get battery in terms of percentages, but calculate fractions
    internally using frac8_t. frac8_t is a percentage expressed in 0-255,
    instead of 0-100. So whenever we get a battery input (event or serial)
    convert to the internal representation.
2025-05-18 Started with layout
    [5x5x3.kicad_pcb, 5x5x3.kicad_sch, SK6812_Mini.step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]
2025-06-22 Connect up the keys, rough placing of components
    Need to find a good switch, and maybe rearrange the row / col pins to
    better align with 5x5 layout.
    Currently targetting 4 layer board
    [5x5x3.kicad_pcb, 5x5x3.kicad_sch]
2025-06-27 Adjusted powerswitch, battery terminal, rotary encoder
    [5x5x3.kicad_pcb, 5x5x3.kicad_sch]
2025-07-06 Routed rows and columns
    [5x5x3.kicad_pcb, 5x5x3.kicad_sch]
2025-08-15 Leds now connected to right pin 0.22
    [5x5x3.kicad_sch]
2025-08-29 Back to 100x100; aim for 5x5x2 hw compat now
    After dithering a long time I am going back to 100x100;
    1. 5x5x3 keyboard can then be used on a 5x5x2 carrier, and vice versa.
    2. I2C oled screen does not fit nicely in the room I had
    3. zmk support for both rgb and i2c powercontrol is in
    development (and has been for some time)
    4. With expressive leds, who needs another screen
    [5x5x3.kicad_pcb]
2025-08-29 Mapped 5x5x2 pins onto 5x5x3
    But there is overlap, so some work is needed. Also, what rubbish am I
    bringing in from the old file?
    [5x5x2.kicad_pcb, 5x5x3.kicad_pcb]
2025-08-30 Routed cols and rows
    [5x5x3.kicad_pcb, 5x5x3.kicad_sch]
2025-08-31 Keyboard routed, added kibuzzard labels on mcu board
    [5x5x3.kicad_pcb]
2025-09-15 Adjusted layer indications, component label legibility, routed mcu
    [5x5x3.kicad_pcb, 5x5x3.kicad_sch]
2025-10-12 Add mcu board logos
2025-10-12 As ordered 20251012 at JLCPCB
    Note that the board file was saved twice and cut up to be sent as
    separate gerbers.
    [b1-B_Cu.gbl, b1-B_Mask.gbs, b1-B_Silkscreen.gbo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]
2026-05-15 Moved to latest zmk
    - zmk at v0.3-123-gead91ca0, zephyr now at 4.1.0
    - zmk now requires HMWv2 layout:
    - New boards/dijkstra/5x5x3/board.yml declaring name/vendor/soc.
    - zmk-config/boards/arm/5x5x3/ → zmk-config/boards/dijkstra/5x5x3/
    - Kconfig.board → Kconfig.5x5x3 with config BOARD_5X5X3 /
    select SOC_NRF52840_QIAA.
    - Kconfig.defconfig now gated by if BOARD_5X5X3; removed obsolete config WS2812_STRIP
    - 5x5x3_defconfig: dropped CONFIG_SOC_SERIES_NRF52X=y /
    CONFIG_SOC_NRF52840_QIAA=y /
    CONFIG_BOARD_5x5x3=y ;
    HWMv2 sets these via Kconfig.5x5x3
    - replaced CONFIG_WS2812_STRIP=y with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
2026-05-15 Adjusted to pins as on the 5x5x3 board
2026-05-16 Add and enable rotary encoder
2026-05-17 Adjust schematic to 5x5x3
2026-05-17 Debugged bluetooth pairing
    There is now a dedicated layer for bluetooth profile management,
    clearing and pin code entering.
    Also: when a layer is changed, all led groups need updating.
